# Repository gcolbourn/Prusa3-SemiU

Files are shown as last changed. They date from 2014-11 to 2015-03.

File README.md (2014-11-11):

# This is Prusa iteration 3 - Semi-Utilitronic Industries edition
Published under GPL v3

All models are in the box_frame folder, including models for aluminium single plate.

Original files from https://github.com/josefprusa/Prusa3, https://github.com/josefprusa/Prusa3-vanilla, http://www.thingiverse.com/thing:18379. Changes:

- minimal Prusa i3 x ends: zip ties, built-in adjustable tensioner and easy z height adjustor.
- increased height on y corners to avoid clearance issue with bed mountings.
- combined mounting holes for hot end -> extruder & extruder -> x-carriage (uses M5x40 bolts).
- strengthened and lengthened extruder idler arms.
- widened a 608ZZ bearing hole on the extruder a bit so it fits better (original extruder by jonaskuehling:
http://www.thingiverse.com/thing:18379)

Stls on Thingiverse as a single build plate for the single plate version: http://www.thingiverse.com/thing:534731

To buy a hardware kit to fit the plastic parts: http://www.emakershop.com/listing?l=1137 (complete without plastic parts) or http://www.emakershop.com/listing?l=768 (hardware only, no plastic parts).

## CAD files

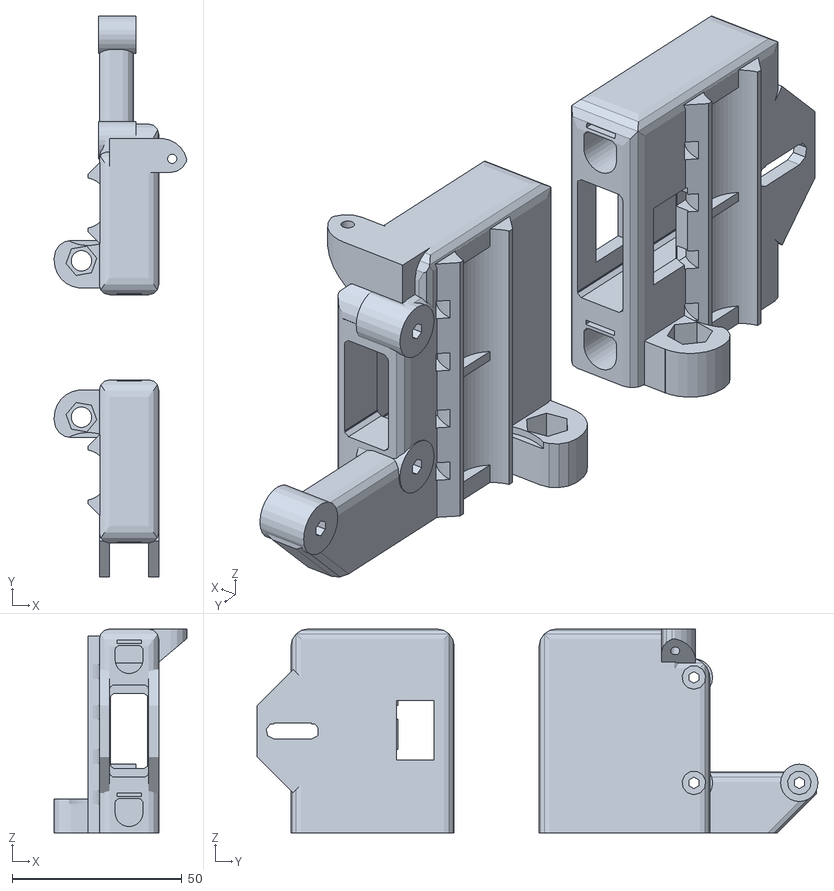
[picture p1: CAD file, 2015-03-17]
box_frame/x-end_zippy_SemiU.stl
39.0 x 165.0 x 60.0

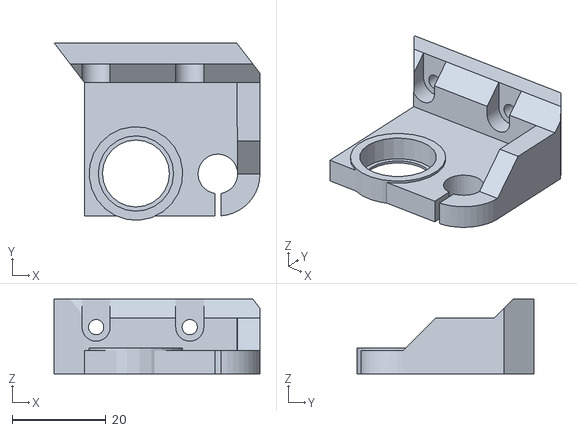
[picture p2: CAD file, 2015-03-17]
box_frame/Z-carrier_right_625.stl
44.0 x 37.9 x 16.0

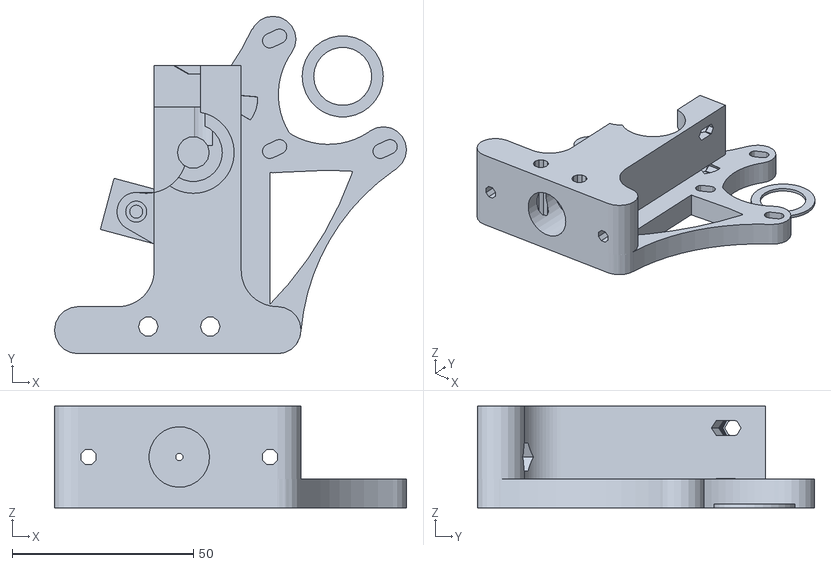
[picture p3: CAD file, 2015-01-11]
box_frame/e1.75.stl
97.1 x 93.1 x 28.0

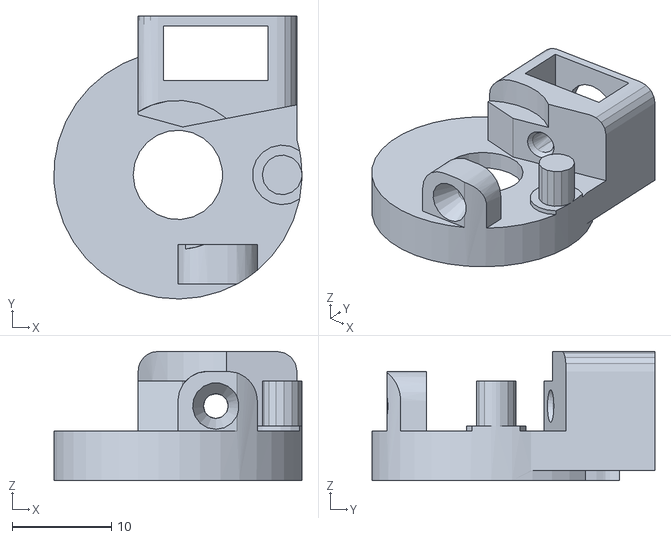
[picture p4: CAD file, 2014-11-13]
box_frame/mini.STL
25.0 x 28.5 x 13.0

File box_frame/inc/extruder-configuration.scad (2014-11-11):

// PRUSA iteration3
// Configuration file
// GNU GPL v3
// Josef Průša <josefprusa@me.com>
// Václav 'ax' Hůla <axtheb@gmail.com>
// http://www.reprap.org/wiki/Prusa_Mendel
// http://github.com/prusajr/PrusaMendel

// PLEASE SELECT ONE OF THE CONFIGURATIONS BELOW
// BY UN-COMMENTING IT

// Uncomment for metric settings
// METRIC METRIC METRIC METRIC METRIC METRIC METRIC METRIC 

include <extruder-metric.scad>;

// Custom settings here, tailor to your supplies and print settings

// Select your belt type ******************************************************

//T2.5
belt_tooth_distance = 2.5;
belt_tooth_ratio = 0.5;

//T5 (strongly discouraged)
//belt_tooth_distance = 5;
//belt_tooth_ratio = 0.75;

//HTD3
//belt_tooth_distance = 3;
//belt_tooth_ratio = 0.75;

//MXL
//belt_tooth_distance = 2.032;
//belt_tooth_ratio = 0.64;

//GT2
//belt_tooth_distance = 2;
//belt_tooth_ratio = 0.5;

// Choose bearing/bushing configuration ***************************************

//Choose from:

// 0 = Z as lm[e]8uu, X and Y bushings
// 1 = all bushings
// 2 = all bearings [default. Do not change unless you really know what you are doing]
// DO NOT OFFER 0 or 1 VARIANTS FOR SALE. We really mean that. In the long run it hurts everyone.

bearing_choice = 2;

// Bushing version
// 0 = square igus housings. By igus we mean JFM-0810-10 or GFM-0810-10
// 1 = round igus (works better if printed precisely)
// 2 = bronze self-aligning bushings
bushing_type = 0;

//Bearing version
// 0 = default lm8uu
// 1 = lme8uu
bearing_type = 0;

// Select idler bearing size **************************************************

// 0 = 608 [standard skate bearings]
// 1 = 624 [roughly same diameter as pulley, makes belt parallel so its prettier]

idler_bearing = 0;

// Thickness of the XZ plate board
board_thickness = 12;

//Layer height * width over thickness. Used for idler sleeve
single_wall_width = 0.3*2.2;

// END of custom settings


// You are not supposed to change this
board_to_xz_distance = 26;
xaxis_rod_distance = 45;
carriage_l = 74;
carriage_hole_to_side = 5;
carriage_hole_height = 4;

//calculated from settings

idler_size = (idler_bearing == 0) ? 22 : 13;

//use 4.5 for 608, 2.5 for 624
idler_size_inner_r = (idler_bearing == 0) ? 4.5 : 2.5;

idler_width = (idler_bearing == 0) ? 9 : 5;

// CHANGE ONLY THE STUFF YOU KNOW
// IT WILL REPLACE DEFAULT SETTING

// RODS

// threaded_rod_diameter = 0;
// threaded_rod_diameter_horizontal = 0;
// smooth_bar_diameter = 0;
// smooth_bar_diameter_horizontal = 0;

// Nuts and bolts

// m8_diameter = 0;
// m8_nut_diameter = 0;

// m4_diameter = 0;
// m4_nut_diameter = 0;

// m3_diameter = 0;
// m3_nut_diameter = 0;

// Bushing holder

// bushing_core_diameter = smooth_bar_diameter;
// bushing_material_thickness = 0;

///counted stuff
m3_nut_diameter_bigger = ((m3_nut_diameter  / 2) / cos (180 / 6))*2;

// functions
include <extruder-functions.scad>


// These constants define the geometry of the complete-printer.scad

//x_smooth_rod_length=325;
//y_smooth_rod_length=405;
//z_smooth_rod_length=235;
bed_x_size=225;
bed_y_size=225;

x_smooth_rod_length=450+board_thickness*2+10; // 492 for 16mm thickness; 484 for 12mm thickness
y_smooth_rod_length=470;
z_smooth_rod_length=405;  
bed_x_size=225;
bed_y_size=225;

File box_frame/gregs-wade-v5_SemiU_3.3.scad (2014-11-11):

// Greg's Wade Extruder. 
// It is licensed under the Creative Commons - GNU GPL license. 
//  2010 by GregFrost
// Extruder based on prusa git repo.
// http://www.thingiverse.com/thing:6713
// modified for i3 by vlnofka <vlnofka@gmail.com>

include<inc/extruder-configuration.scad>


///////////////////////////////////////////////////////////////////////////////////////////////////////////////////////
// Define the hotend_mounting style you want by specifying hotend_mount=style1+style2 etc.
//e.g. wade(hotend_mount=groovemount+peek_reprapsource_mount);
malcolm_hotend_mount=1;
groovemount=2;
peek_reprapsource_mount=4;
arcol_mount=8;
mendel_parts_v6_mount=16; 
grrf_peek_mount=32;
wildseyed_mount=64;
geared_extruder_nozzle=128; // http://reprap.org/wiki/Geared_extruder_nozzle
jhead_mount=256;
geeksbase_mount=512;
malcolm_extrusion_mount=1024;	//broken

//default_extruder_mount=malcolm_extrusion_mount;
//default_extruder_mount=groovemount;
default_extruder_mount=256;

// Nut wrench sizes ISO 4032
m3_wrench = 5.5;
m4_wrench = 7;

///////////////////////////////////////////////////////////////////////////////////////////////////////////////////////

mounting_holes_legacy=1;
mounting_holes_symmetrical=2;
default_mounting_holes=mounting_holes_symmetrical;

///////////////////////////////////////////////////////////////////////////////////////////////////////////////////////

wade(hotend_mount=default_extruder_mount,
	mounting_holes=default_mounting_holes);

////CarriageVisualisation
color("red")
//x-carriage v2
translate([24,-32.75,base_extra_depth+wade_block_depth]) 
  rotate([0,0,0]) 
    import("../output/x-carriageV2.stl");


//%translate([45.0, 55.50, 1]) //[46.78,55, 1]
//  rotate([0, 0, 0])
//    nema17(places=[0,1,1,1], holes=true, shadow=5);

/*
color("silver")
translate(large_wheel_translation) {
	translate([0,0,-15])import("../output/biggearmod_fixed.stl");
	rotate([0,0,29.5]) translate([gear_separation,0, 5]) {
		rotate([180,0,0]) import("../output/smallgearmod_fixed.stl");
		rotate([0,0,-29.5]) translate([0,0,-4]) {nema17(places=[0,1,1,1], holes=true, shadow=5, $fn=7, h=8);
		}
	}
}
*/
translate([52,70,0]) bearing_washer();


////Place for assembly.
//translate([50,56,15.25]) // This is the translation for the 3mm version.
////translate([50,56,13.92]) // This is the translation for the 1.75mm version.
//rotate(180)
//Place for printing
translate([-20,0,15.25])
rotate([0,-90,0])
wadeidler(); 

///////////////////////////////////////////////////////////////////////////////////////////////////////////////////////
/**
 * Extruder
 * @name Extruder
 * @assembled
 * @using 1 small-gear
 * @id extruder
 * @using 1 idler
 * @using 1 extruder-body
 * @using 1 m3nut
 * @using 1 m3washer
 * @using 1 m3x25
 * @step Take idler and insert nut into small nut-trap inside the hinge.
 * @step While holding the nut in place, preprare M3x25 bolt with washer and screw it into the hinge just enough to hold the nut.
 * @step Now take the extruder body and idler. Place idler on the hinge counterpart and compleately screw the M3x25 bolt. This will create secured hinge.
 * 
 * @using 2 m4nut
 * @step Place M4 nuts into their nut traps, secure them with piece of tape. We need them in place, since later they would be harder to access.
 * 
 * @using 3 m3x10
 * @using 3 m3washer
 * @using 1 NEMA17
 * @step Prepare your NEMA17 stepper motor and three M3x10 screws with washers.
 * @step Hold motor on place and lightly tighten the screws. We need to adjust motor position later, no need to tighten it hard.
 * 
 * @using 1 large-gear
 * @using 1 m8washer
 * @using 2 m8nut
 * @using 2 bearing-608
 * @step Place two skate bearings on ther position, they should snuggly fit in.
 * @step Insert prepared large gear into the body with mounted bearings.
 * @step Check if the alignment of hobbed part with the filament path. Adjust it accordingly with adding or removing M8 washers.
 * @step After adjusting, we need to fix the bolt in. So we place washer at the end of hobbed bolt and with two M8 nuts we will do locknut by tightening them against each other.
 * @step Check if large gear turns freely.
 * 
 * @using 2 m3x40
 * @using 4 m3washer
 * @using 2 extruder-spring
 * @step Prepare two M3x40 screws with sandwitch of washer-spring-washer.
 * @step Insert two M3 nuts into nut traps on top of drive mechanism. [[extruder/top-nut-traps.png]]
 * @step Insert prepared screws into the holes on idler. Close the idler and tighten the screws into the trapped nuts. More you tighten those screws, more pressure will be on fillament.
 * @step Your extruder is done. [[extruder/assembled.jpg]]
 */

/**
 * Extruder body
 * @name Extruder body
 * @category Printed
 * @id extruder-body
 */

/**
 * Extruder idler
 * @name Extruder Idler
 * @id idler
 * @category Printed
 * @using 1 bearing-608
 * @using 1 idler-m8-piece
 * @step Insert piece of M8 rod into bearing.
 * @step Insert 608 bearing with rod into printed idler part.
 */

/**
 * Small M8 rod 
 * @name Idler
 * @id idler-m8-piece
 * @category Rods and Bars
 */

/**
 * Spring used for idler on extruder.
 * @name Extruder spring
 * @id extruder-spring
 */

//===================================================
// Parameters defining the wade body:

elevation = 15;
wade_block_height=55+elevation+3;
wade_block_width=24;
wade_block_depth=28;

block_bevel_r=10;

base_thickness=13;
//base_length=66;
base_length=55;
//base_leadout=22;
base_leadout=21;
//base_extra_depth=11;
base_extra_depth=0;

nema17_hole_spacing=1.2*25.4;//31; 
nema17_width=1.7*25.4;
nema17_support_d=nema17_width-nema17_hole_spacing;

screw_head_recess_diameter=7.2;
screw_head_recess_depth=3;

motor_mount_rotation=0;
motor_mount_translation=[48,50+elevation,0];
//motor_mount_translation=[52.5,38,0]; //original
motor_mount_thickness=8;

large_wheel_translation=[50.5-(7.4444+32.0111+0.25),34+elevation,0];

m8_clearance_hole=8.8;
//hole_for_608=22.3;
hole_for_608=22.5;
608_diameter=22;

block_top_right=[wade_block_width,wade_block_height];

layer_thickness=0.3; //0.35;
filament_diameter=3;
filament_feed_hole_d=(filament_diameter*1.1)/cos(180/8);
//hobbing_depth=2;
hobbing_depth=1;
echo ("filament_feed_hole_d", filament_feed_hole_d);

//This is the distance from the centre of the filament to the centre of the hobbed bolt.
filament_feed_hole_offset=8/2-hobbing_depth+filament_diameter/2;

echo ("filament_feed_hole_offset", filament_feed_hole_offset);

idler_nut_trap_depth=7.5;
idler_nut_thickness=4;

gear_separation=7.4444+32.0111+0.25;

function motor_hole(hole)=[
	motor_mount_translation[0],
	motor_mount_translation[1]]+
	rotated(45+motor_mount_rotation+hole*90)*nema17_hole_spacing/sqrt(2);

// Parameters defining the idler.

filament_pinch=[
	large_wheel_translation[0]-filament_feed_hole_offset-filament_diameter/2,
	large_wheel_translation[1],
	wade_block_depth/2];
idler_axis=filament_pinch-[608_diameter/2,0,0];
idler_fulcrum_offset=608_diameter/2+3.5+m3_diameter/2;
idler_fulcrum=idler_axis-[0,idler_fulcrum_offset,0];
idler_corners_radius=4; 
idler_height=12;
idler_608_diameter=608_diameter+2;
idler_608_height=9;
idler_mounting_hole_across=8;
idler_mounting_hole_up=15;
idler_short_side=wade_block_depth-2;
idler_hinge_r=m3_diameter/2+3.5;
idler_hinge_width=6.5;
idler_end_length=(idler_height-2)+5;
idler_mounting_hole_diameter=m4_diameter+0.25;
idler_mounting_hole_elongation=1;
idler_long_top=idler_mounting_hole_up+idler_mounting_hole_diameter/2+idler_mounting_hole_elongation+2.5;
idler_long_bottom=idler_fulcrum_offset;
idler_long_side=idler_long_top+idler_long_bottom;

module bearing_washer()
{
	difference()
	{
		cylinder(r=hole_for_608/2-0.05,h=1);
		translate([0,0,-1])
		cylinder(r=8,h=3);
	}
}

module wade(
	hotend_mount=default_extruder_mount,
	mounting_holes=default_mounting_holes)
{
	difference ()
	{
		union()
		{
			// The wade block.
			cube([wade_block_width,wade_block_height,wade_block_depth]);

			// Filler between wade block and motor mount.
			translate([10-2,0,0])
			cube([wade_block_width,
				wade_block_height,
				motor_mount_thickness]);

			// Round the ends of the base
			translate([base_length-base_leadout,0,0])
			cylinder(r=base_thickness/2,h=wade_block_depth+base_extra_depth,$fn=20);

			translate([-base_leadout,0,0])
			cylinder(r=base_thickness/2,h=wade_block_depth+base_extra_depth,$fn=20);

			//Provide the bevel betweeen the base and the wade block.
			render()
			difference()
			{
				translate([-block_bevel_r,0,0])
				cube([block_bevel_r*2+wade_block_width,
					base_thickness/2+block_bevel_r,wade_block_depth+base_extra_depth]);				
				translate([-block_bevel_r,block_bevel_r+base_thickness/2])
				cylinder(r=block_bevel_r,h=wade_block_depth+base_extra_depth,$fn=60);
				translate([wade_block_width+block_bevel_r,
					block_bevel_r+base_thickness/2])
				cylinder(r=block_bevel_r,h=wade_block_depth+base_extra_depth,$fn=60);
			}
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

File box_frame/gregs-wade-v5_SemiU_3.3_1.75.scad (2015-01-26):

// Greg's Wade Extruder. 
// It is licensed under the Creative Commons - GNU GPL license. 
//  2010 by GregFrost
// Extruder based on prusa git repo.
// http://www.thingiverse.com/thing:6713
// modified for i3 by vlnofka <vlnofka@gmail.com>

include<inc/extruder-configuration.scad>


///////////////////////////////////////////////////////////////////////////////////////////////////////////////////////
// Define the hotend_mounting style you want by specifying hotend_mount=style1+style2 etc.
//e.g. wade(hotend_mount=groovemount+peek_reprapsource_mount);
malcolm_hotend_mount=1;
groovemount=2;
peek_reprapsource_mount=4;
arcol_mount=8;
mendel_parts_v6_mount=16; 
grrf_peek_mount=32;
wildseyed_mount=64;
geared_extruder_nozzle=128; // http://reprap.org/wiki/Geared_extruder_nozzle
jhead_mount=256;
geeksbase_mount=512;
malcolm_extrusion_mount=1024;	//broken

//default_extruder_mount=malcolm_extrusion_mount;
//default_extruder_mount=groovemount;
default_extruder_mount=256;

// Nut wrench sizes ISO 4032
m3_wrench = 5.5;
m4_wrench = 7;

///////////////////////////////////////////////////////////////////////////////////////////////////////////////////////

mounting_holes_legacy=1;
mounting_holes_symmetrical=2;
default_mounting_holes=mounting_holes_symmetrical;

///////////////////////////////////////////////////////////////////////////////////////////////////////////////////////

wade(hotend_mount=default_extruder_mount,
	mounting_holes=default_mounting_holes);

////CarriageVisualisation
color("red")
//x-carriage v2
translate([24,-32.75,base_extra_depth+wade_block_depth]) 
  rotate([0,0,0]) 
    import("../output/x-carriageV2.stl");


//%translate([45.0, 55.50, 1]) //[46.78,55, 1]
//  rotate([0, 0, 0])
//    nema17(places=[0,1,1,1], holes=true, shadow=5);

/*
color("silver")
translate(large_wheel_translation) {
	translate([0,0,-15])import("../output/biggearmod_fixed.stl");
	rotate([0,0,29.5]) translate([gear_separation,0, 5]) {
		rotate([180,0,0]) import("../output/smallgearmod_fixed.stl");
		rotate([0,0,-29.5]) translate([0,0,-4]) {nema17(places=[0,1,1,1], holes=true, shadow=5, $fn=7, h=8);
		}
	}
}
*/
translate([52,70,0]) bearing_washer();


////Place for assembly.
//translate([50,56,15.25]) // This is the translation for the 3mm version.
////translate([50,56,13.92]) // This is the translation for the 1.75mm version.
//rotate(180)
//Place for printing
translate([-20,0,15.25])
rotate([0,-90,0])
wadeidler(); 

///////////////////////////////////////////////////////////////////////////////////////////////////////////////////////
/**
 * Extruder
 * @name Extruder
 * @assembled
 * @using 1 small-gear
 * @id extruder
 * @using 1 idler
 * @using 1 extruder-body
 * @using 1 m3nut
 * @using 1 m3washer
 * @using 1 m3x25
 * @step Take idler and insert nut into small nut-trap inside the hinge.
 * @step While holding the nut in place, preprare M3x25 bolt with washer and screw it into the hinge just enough to hold the nut.
 * @step Now take the extruder body and idler. Place idler on the hinge counterpart and compleately screw the M3x25 bolt. This will create secured hinge.
 * 
 * @using 2 m4nut
 * @step Place M4 nuts into their nut traps, secure them with piece of tape. We need them in place, since later they would be harder to access.
 * 
 * @using 3 m3x10
 * @using 3 m3washer
 * @using 1 NEMA17
 * @step Prepare your NEMA17 stepper motor and three M3x10 screws with washers.
 * @step Hold motor on place and lightly tighten the screws. We need to adjust motor position later, no need to tighten it hard.
 * 
 * @using 1 large-gear
 * @using 1 m8washer
 * @using 2 m8nut
 * @using 2 bearing-608
 * @step Place two skate bearings on ther position, they should snuggly fit in.
 * @step Insert prepared large gear into the body with mounted bearings.
 * @step Check if the alignment of hobbed part with the filament path. Adjust it accordingly with adding or removing M8 washers.
 * @step After adjusting, we need to fix the bolt in. So we place washer at the end of hobbed bolt and with two M8 nuts we will do locknut by tightening them against each other.
 * @step Check if large gear turns freely.
 * 
 * @using 2 m3x40
 * @using 4 m3washer
 * @using 2 extruder-spring
 * @step Prepare two M3x40 screws with sandwitch of washer-spring-washer.
 * @step Insert two M3 nuts into nut traps on top of drive mechanism. [[extruder/top-nut-traps.png]]
 * @step Insert prepared screws into the holes on idler. Close the idler and tighten the screws into the trapped nuts. More you tighten those screws, more pressure will be on fillament.
 * @step Your extruder is done. [[extruder/assembled.jpg]]
 */

/**
 * Extruder body
 * @name Extruder body
 * @category Printed
 * @id extruder-body
 */

/**
 * Extruder idler
 * @name Extruder Idler
 * @id idler
 * @category Printed
 * @using 1 bearing-608
 * @using 1 idler-m8-piece
 * @step Insert piece of M8 rod into bearing.
 * @step Insert 608 bearing with rod into printed idler part.
 */

/**
 * Small M8 rod 
 * @name Idler
 * @id idler-m8-piece
 * @category Rods and Bars
 */

/**
 * Spring used for idler on extruder.
 * @name Extruder spring
 * @id extruder-spring
 */

//===================================================
// Parameters defining the wade body:

elevation = 15;
wade_block_height=55+elevation+3;
wade_block_width=24;
wade_block_depth=28;

block_bevel_r=10;

base_thickness=13;
//base_length=66;
base_length=55;
//base_leadout=22;
base_leadout=21;
//base_extra_depth=11;
base_extra_depth=0;

nema17_hole_spacing=1.2*25.4;//31; 
nema17_width=1.7*25.4;
nema17_support_d=nema17_width-nema17_hole_spacing;

screw_head_recess_diameter=7.2;
screw_head_recess_depth=3;

motor_mount_rotation=0;
motor_mount_translation=[48,50+elevation,0];
//motor_mount_translation=[52.5,38,0]; //original
motor_mount_thickness=8;

large_wheel_translation=[50.5-(7.4444+32.0111+0.25),34+elevation,0];

m8_clearance_hole=8.8;
//hole_for_608=22.3;
hole_for_608=22.5;
608_diameter=22;

block_top_right=[wade_block_width,wade_block_height];

layer_thickness=0.3; //0.35;
filament_diameter=4;//for 2mm ID 4mm OD PFTE tube for 1.75mm filament
filament_feed_hole_d=(filament_diameter*1.1)/cos(180/8);
//hobbing_depth=2;
hobbing_depth=1;
echo ("filament_feed_hole_d", filament_feed_hole_d);

//This is the distance from the centre of the filament to the centre of the hobbed bolt.
filament_feed_hole_offset=8/2-hobbing_depth+filament_diameter/2;

echo ("filament_feed_hole_offset", filament_feed_hole_offset);

idler_nut_trap_depth=7.5;
idler_nut_thickness=4;

gear_separation=7.4444+32.0111+0.25;

function motor_hole(hole)=[
	motor_mount_translation[0],
	motor_mount_translation[1]]+
	rotated(45+motor_mount_rotation+hole*90)*nema17_hole_spacing/sqrt(2);

// Parameters defining the idler.

filament_pinch=[
	large_wheel_translation[0]-filament_feed_hole_offset-filament_diameter/2,
	large_wheel_translation[1],
	wade_block_depth/2];
idler_axis=filament_pinch-[608_diameter/2,0,0];
idler_fulcrum_offset=608_diameter/2+3.5+m3_diameter/2;
idler_fulcrum=idler_axis-[0,idler_fulcrum_offset,0];
idler_corners_radius=4; 
idler_height=12;
idler_608_diameter=608_diameter+2;
idler_608_height=9;
idler_mounting_hole_across=8;
idler_mounting_hole_up=15;
idler_short_side=wade_block_depth-2;
idler_hinge_r=m3_diameter/2+3.5;
idler_hinge_width=6.5;
idler_end_length=(idler_height-2)+5;
idler_mounting_hole_diameter=m4_diameter+0.25;
idler_mounting_hole_elongation=1;
idler_long_top=idler_mounting_hole_up+idler_mounting_hole_diameter/2+idler_mounting_hole_elongation+2.5;
idler_long_bottom=idler_fulcrum_offset;
idler_long_side=idler_long_top+idler_long_bottom;

module bearing_washer()
{
	difference()
	{
		cylinder(r=hole_for_608/2-0.05,h=1);
		translate([0,0,-1])
		cylinder(r=8,h=3);
	}
}

module wade(
	hotend_mount=default_extruder_mount,
	mounting_holes=default_mounting_holes)
{
	difference ()
	{
		union()
		{
			// The wade block.
			cube([wade_block_width,wade_block_height,wade_block_depth]);

			// Filler between wade block and motor mount.
			translate([10-2,0,0])
			cube([wade_block_width,
				wade_block_height,
				motor_mount_thickness]);

			// Round the ends of the base
			translate([base_length-base_leadout,0,0])
			cylinder(r=base_thickness/2,h=wade_block_depth+base_extra_depth,$fn=20);

			translate([-base_leadout,0,0])
			cylinder(r=base_thickness/2,h=wade_block_depth+base_extra_depth,$fn=20);

			//Provide the bevel betweeen the base and the wade block.
			render()
			difference()
			{
				translate([-block_bevel_r,0,0])
				cube([block_bevel_r*2+wade_block_width,
					base_thickness/2+block_bevel_r,wade_block_depth+base_extra_depth]);				
				translate([-block_bevel_r,block_bevel_r+base_thickness/2])
				cylinder(r=block_bevel_r,h=wade_block_depth+base_extra_depth,$fn=60);
				translate([wade_block_width+block_bevel_r,
					block_bevel_r+base_thickness/2])
				cylinder(r=block_bevel_r,h=wade_block_depth+base_extra_depth,$fn=60);
			}
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

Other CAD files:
box_frame/Z-carrier_left_625.stl
box_frame/inc/xcarr-configuration.scad
box_frame/Guidler-SemiU3.scad
box_frame/Guidler-SemiU3_1.75.scad
box_frame/Simple_mechanical_endstop_holder_for_8mm_rod_for_V1.2a.scad
box_frame/inc/bearing_new.scad
box_frame/inc/extruder-functions.scad
box_frame/inc/extruder-metric.scad
box_frame/inc/xcarr-bearing.scad
box_frame/minimal_plastic_spring_extruder.scad
box_frame/spring4.scad
box_frame/x-carriageV2.1-SemiU_3.scad
box_frame/x-end_zippy_SemiU.scad
box_frame/x-end_zippy_z_isolator_SemiU.scad
box_frame/y-corners_SemiU.scad
box_frame/z-axis-bottom.scad
box_frame/z-axis-top.scad
box_frame/z-isolators_SemiU.scad
box_frame/z-isolators_SemiU_less_contact.scad

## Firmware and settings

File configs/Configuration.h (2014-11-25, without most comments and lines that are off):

#define CONFIGURATION_H
#define STRING_VERSION_CONFIG_H __DATE__ " " __TIME__ // build date and time
#define STRING_CONFIG_H_AUTHOR "(none, default config)" // Who made the changes.
#define SERIAL_PORT 0
#define BAUDRATE 250000
#define MOTHERBOARD 33
#define EXTRUDERS 1
#define POWER_SUPPLY 1
#define TEMP_SENSOR_0 1
#define TEMP_SENSOR_1 1
#define TEMP_SENSOR_2 0
#define TEMP_SENSOR_BED 1
#define MAX_REDUNDANT_TEMP_SENSOR_DIFF 10
#define TEMP_RESIDENCY_TIME 10  // (seconds)
#define TEMP_HYSTERESIS 3       // (degC) range of +/- temperatures considered "close" to the target one
#define TEMP_WINDOW     1       // (degC) Window around target to start the residency timer x degC early.
#define HEATER_0_MINTEMP 5
#define HEATER_1_MINTEMP 5
#define HEATER_2_MINTEMP 5
#define BED_MINTEMP 5
#define HEATER_0_MAXTEMP 275
#define HEATER_1_MAXTEMP 275
#define HEATER_2_MAXTEMP 275
#define BED_MAXTEMP 150
#define PIDTEMP
#define BANG_MAX 255 // limits current to nozzle while in bang-bang mode; 255=full current
#define PID_MAX 255 // limits current to nozzle while PID is active (see PID_FUNCTIONAL_RANGE below); 255=full current
  #define PID_FUNCTIONAL_RANGE 10 // If the temperature difference between the target temperature and the actual temperature
  #define PID_INTEGRAL_DRIVE_MAX 255  //limit for the integral term
  #define K1 0.95 //smoothing factor within the PID
  #define PID_dT ((16.0 * 8.0)/(F_CPU / 64.0 / 256.0)) //sampling period of the temperature routine
#define DEFAULT_Kp 12.6
#define DEFAULT_Ki 0.66
#define DEFAULT_Kd 60.6
#define MAX_BED_POWER 255 // limits duty cycle to bed; 255=full current
#define PREVENT_DANGEROUS_EXTRUDE
#define PREVENT_LENGTHY_EXTRUDE
#define EXTRUDE_MINTEMP 170
#define EXTRUDE_MAXLENGTH (X_MAX_LENGTH+Y_MAX_LENGTH) //prevent extrusion of very large distances.
#define ENDSTOPPULLUPS // Comment this out (using // at the start of the line) to disable the endstop pullup resistors
  #define ENDSTOPPULLUP_XMAX
  #define ENDSTOPPULLUP_YMAX
  #define ENDSTOPPULLUP_ZMAX
  #define ENDSTOPPULLUP_XMIN
  #define ENDSTOPPULLUP_YMIN
  #define ENDSTOPPULLUP_ZMIN
const bool X_MIN_ENDSTOP_INVERTING = false; // set to true to invert the logic of the endstop.
const bool Y_MIN_ENDSTOP_INVERTING = false; // set to true to invert the logic of the endstop.
const bool Z_MIN_ENDSTOP_INVERTING = false; // set to true to invert the logic of the endstop.
const bool X_MAX_ENDSTOP_INVERTING = true; // set to true to invert the logic of the endstop.
const bool Y_MAX_ENDSTOP_INVERTING = true; // set to true to invert the logic of the endstop.
const bool Z_MAX_ENDSTOP_INVERTING = true; // set to true to invert the logic of the endstop.
#if defined(COREXY) && !defined(DISABLE_MAX_ENDSTOPS)
  #define DISABLE_MAX_ENDSTOPS
#endif
#define X_ENABLE_ON 0
#define Y_ENABLE_ON 0
#define Z_ENABLE_ON 0
#define E_ENABLE_ON 0 // For all extruders
#define DISABLE_X false
#define DISABLE_Y false
#define DISABLE_Z false
#define DISABLE_E false // For all extruders
#define DISABLE_INACTIVE_EXTRUDER true //disable only inactive extruders and keep active extruder enabled (needed for Windows compilation to work)
#define INVERT_X_DIR false   // for Mendel set to false, for Orca set to true
#define INVERT_Y_DIR false    // for Mendel set to true, for Orca set to false
#define INVERT_Z_DIR false    // for Mendel set to false, for Orca set to true
#define INVERT_E0_DIR true   // for direct drive extruder v9 set to true, for geared extruder set to false
#define INVERT_E1_DIR false    // for direct drive extruder v9 set to true, for geared extruder set to false
#define INVERT_E2_DIR false   // for direct drive extruder v9 set to true, for geared extruder set to false
#define X_HOME_DIR -1
#define Y_HOME_DIR -1
#define Z_HOME_DIR -1
#define min_software_endstops true // If true, axis won't move to coordinates less than HOME_POS.
#define max_software_endstops true  // If true, axis won't move to coordinates greater than the defined lengths below.
#define X_MAX_POS 205
#define X_MIN_POS 0
#define Y_MAX_POS 205
#define Y_MIN_POS 0
#define Z_MAX_POS 200
#define Z_MIN_POS 0
#define X_MAX_LENGTH (X_MAX_POS - X_MIN_POS)
#define Y_MAX_LENGTH (Y_MAX_POS - Y_MIN_POS)
#define Z_MAX_LENGTH (Z_MAX_POS - Z_MIN_POS)
#define MANUAL_X_HOME_POS 0
#define MANUAL_Y_HOME_POS 0
#define MANUAL_Z_HOME_POS 0
#define NUM_AXIS 4 // The axis order in all axis related arrays is X, Y, Z, E
#define HOMING_FEEDRATE {50*60, 50*60, 3*60, 0}  // set the homing speeds (mm/min)
#define DEFAULT_AXIS_STEPS_PER_UNIT   {80.0,80.0,4000.0,700}  // default steps per unit for i3
#define DEFAULT_MAX_FEEDRATE          {500, 500, 5, 25}    // (mm/sec)
#define DEFAULT_MAX_ACCELERATION      {2500,2500,100,10000}    // X, Y, Z, E maximum start speed for accelerated moves. E default values are good for skeinforge 40+, for older versions raise them a lot.
#define DEFAULT_ACCELERATION          3000    // X, Y, Z and E max acceleration in mm/s^2 for printing moves
#define DEFAULT_RETRACT_ACCELERATION  3000   // X, Y, Z and E max acceleration in mm/s^2 for retracts
#define DEFAULT_XYJERK                20.0    // (mm/sec)
#define DEFAULT_ZJERK                 0.4     // (mm/sec)
#define DEFAULT_EJERK                 5.0    // (mm/sec)
#define PLA_PREHEAT_HOTEND_TEMP 180
#define PLA_PREHEAT_HPB_TEMP 70
#define PLA_PREHEAT_FAN_SPEED 255   // Insert Value between 0 and 255
#define ABS_PREHEAT_HOTEND_TEMP 240
#define ABS_PREHEAT_HPB_TEMP 100
#define ABS_PREHEAT_FAN_SPEED 255   // Insert Value between 0 and 255
#define ULTIMAKERCONTROLLER //as available from the ultimaker online store.
 #define ULTIPANEL
 #define NEWPANEL
  #define SDSUPPORT
  #define ULTRA_LCD
    #define LCD_WIDTH 20
    #define LCD_HEIGHT 4
#define SOFT_PWM_SCALE 0
#include "Configuration_adv.h"
#include "thermistortables.h"

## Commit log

2014-11-11 SemiU Prusa i3 kit
    - minimal Prusa i3 x ends: zip ties, built-in adjustable tensioner and
    easy z height adjustor.
    - increased height on y corners to avoid clearance issue with bed
    mountings.
    - combined mounting holes for hot end -> extruder & extruder ->
    x-carriage (uses M5x40 bolts).
    - strengthened and lengthened extruder idler arms.
    - widened a 608ZZ bearing hole on the extruder a bit so it fits better
    (original extruder by jonaskuehling:
    http://www.thingiverse.com/thing:18379)
    - On Thingiverse as a single build plate stl for the single plate
    version: http://www.thingiverse.com/thing:534731
    [bearing_new.scad, extruder-configuration.scad, extruder-functions.scad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]
2014-11-13 Added minimal_plastic_spring_extruder
    See: http://www.thingiverse.com/thing:542498
    Inspired by http://www.thingiverse.com/thing:411462, but designed from
    scratch in OpenSCAD, using http://www.thingiverse.com/thing:46749.
    Added spring for tensioning without any additional hardware. For Mk8
    drive gear, 3mm filament and 624ZZ bearing. Currently untested, so
    dimensions and spring constant likely wrong.
    To do:
    - test spring
    - add finger pull
    - add filament guides
    - add dust box
    - add hot end/bowden mount
    - add fan mount(s)
    - add x carriage
    [mini.STL, minimal_plastic_spring_extruder.scad, minimal_plastic_spring_extruder.stl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]
2014-11-13 Prototype 2 of minimal plastic-spring extruder
    NEMA17 shaft hole bigger; plate to cover NEMA17 recess; beefing up of
    spring join to NEMA mount plate.
    [minimal_plastic_spring_extruder.scad]
2014-11-13 Gear slot depth -> 1 mm
    Also NEMA17 shaft hole 0.1 mm wider
    [minimal_plastic_spring_extruder.scad, minimal_plastic_spring_extruder.stl]
2014-11-13 Added finger pull
    [minimal_plastic_spring_extruder.scad, minimal_plastic_spring_extruder.stl]
2014-11-13 Added parameters
    drive_gear_bottom_shaft_height & vertical_offset_for_rotation
    [minimal_plastic_spring_extruder.scad]
2014-11-13 Coordinate system centred on NEMA17 axis
    [minimal_plastic_spring_extruder.scad]
2014-11-13 tidied up
    Cleaned up parameterisation
    [minimal_plastic_spring_extruder.scad]
2014-11-13 Removed 0 translates
    [minimal_plastic_spring_extruder.scad]
2014-11-13 tidied up intro listing of parameters
    [minimal_plastic_spring_extruder.scad]
2014-11-13 swaped some more numbers for parameters
    [minimal_plastic_spring_extruder.scad]
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2014-11-13 corrections and tidying up
    [minimal_plastic_spring_extruder.scad]
2014-11-13 Added foot near ring pull
    [minimal_plastic_spring_extruder.scad]
2014-11-13 Added motor mount holes
    [minimal_plastic_spring_extruder.scad]
2014-11-20 Split height into filament and spring height
    Split height into filament_height and spring_height; also added
    filament path
    [minimal_plastic_spring_extruder.scad]
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2014-11-21 Added dustbox to minimal exruder
    [minimal_plastic_spring_extruder.scad]
2014-11-21 Corrected filament x position
    [minimal_plastic_spring_extruder.scad]
2014-11-21 Added hot end mount
    [minimal_plastic_spring_extruder.scad]
2014-11-21 Added cable tie for hot end
    [minimal_plastic_spring_extruder.scad]
2014-11-21 Tidied up hot end mount code
    [minimal_plastic_spring_extruder.scad]
2014-11-21 deleted old hot end mount code
    [minimal_plastic_spring_extruder.scad]
2014-11-21 cut out motor shroud on hot end mount
    [minimal_plastic_spring_extruder.scad]
2014-11-21 Cut filament hole in dustbox
    [minimal_plastic_spring_extruder.scad]
2014-11-21 added thin sheet for printing without support
    [minimal_plastic_spring_extruder.scad]
2014-11-21 cut cable tie hole from bottom plate
    [minimal_plastic_spring_extruder.scad]
2014-11-21 modularised cable tie hole; subtracted from sheet
    [minimal_plastic_spring_extruder.scad]
2014-11-21 changed thin support plate to circle
    [minimal_plastic_spring_extruder.scad]
2014-11-21 added hole for M3x6 bolt
    [minimal_plastic_spring_extruder.scad]
2014-11-21 made dustbox 3mm bigger
    [minimal_plastic_spring_extruder.scad]
2014-11-21 made dustbox deeper and cut out from shroud
    [minimal_plastic_spring_extruder.scad]
2014-11-25 added Marlin and Slic3r configs
    [Configuration.h]
2014-11-25 Corrected nozzle size 0.5 -> 0.4
2014-12-01 corrections to minimal extruder
    [minimal_plastic_spring_extruder.scad]
2015-01-11 1.75mm extruder and guidler
    [Guidler-SemiU3.scad, Guidler-SemiU3_1.75.scad, e1.75.stl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]
2015-01-22 Added simple endstop holder (J shaped)
    [Simple_mechanical_endstop_holder_for_8mm_rod_V2.scad]
2015-01-26 1.75mm extruder - 4mm hole for 2mm ID 4mm OD PFTE
    [Simple_mechanical_endstop_holder_for_8mm_rod_V2.scad, Simple_mechanical_endstop_holder_for_8mm_rod_for_V1.2.scad, gregs-wade-v5_SemiU_3.3_1.75.scad]
2015-01-30 put nut traps on endstop holder on other side
    [Simple_mechanical_endstop_holder_for_8mm_rod_for_V1.2a.scad]
2015-01-30 removed old version of endstop holder
    [Simple_mechanical_endstop_holder_for_8mm_rod_for_V1.2.scad]
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2015-03-14 added drag chain connector to x motor piece
    [x-end_zippy_z_isolator_SemiU.scad]
2015-03-15 made drag chain mounts the same size
    [x-end_zippy_z_isolator_SemiU.scad]
2015-03-15 moved drag chain mount to back of x motor part
    [x-end_zippy_z_isolator_SemiU.scad]
2015-03-15 made m5 nut traps on z isolators a bit bigger
    [z-isolators_SemiU.scad]
2015-03-15 z isolators - added m8 rod guide
    [z-isolators_SemiU.scad]
2015-03-16 adjusted drag chain mount on x motor piece
    [x-end_zippy_z_isolator_SemiU.scad]
2015-03-16 adjusted M8 smooth rod holes on z isolators
    [z-isolators_SemiU.scad]
2015-03-16 moved drag chain mounts to back of x motor piece (again)
    [x-end_zippy_z_isolator_SemiU.scad]
2015-03-16 z isolator: adjusted M8 rod position and put in support for holes on
    [z-isolators_SemiU.scad]
2015-03-16 made drag chain mount hole a bit bigger
    [x-end_zippy_z_isolator_SemiU.scad]
2015-03-17 added M3x10 mount for z endstop on z isolators
    [z-isolators_SemiU.scad]
2015-03-17 Added 625ZZ z top stablilisers (stl only from http://www.thingiverse.com/thing:719760)
    [Z-carrier_left_625.stl, Z-carrier_right_625.stl]
2015-03-17 z isolators - spaced out m5 nuts more, lifted endstop 1mm
    [z-isolators_SemiU.scad]
2015-03-17 z isolators - added back in other part
    [z-isolators_SemiU.scad]
2015-03-17 z isolators - made m5 hole smaller
    [x-end_zippy_SemiU.stl, z-isolators_SemiU.scad]
2015-03-19 z isolator - made hole tolerances tighter
    [z-isolators_SemiU.scad]
2015-03-19 z isolator - tightened hole tolerances
    [z-isolators_SemiU.scad]
2015-03-19 z isolators - added less contact version
    [z-isolators_SemiU_less_contact.scad]
2015-03-19 x motor piece - moved z endstop probe
    [x-end_zippy_z_isolator_SemiU.scad]
2015-03-25 z isolators with less contact (with x end)
    [z-isolators_SemiU_less_contact.scad]
2015-03-25 adjusted tolerances and endstop position on z isolator
    [x-end_zippy_z_isolator_SemiU.scad, z-isolators_SemiU.scad]
